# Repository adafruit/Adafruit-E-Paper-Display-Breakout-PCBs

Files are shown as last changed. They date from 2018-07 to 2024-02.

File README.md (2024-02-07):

# Adafruit-E-Paper-Display-Breakout-PCBs
PCB files for Adafruit E-Paper Display Breakouts

Format is EagleCAD schematic and board layout

For more details, check out the product page at

   * https://www.adafruit.com/product/1028   
   * https://www.adafruit.com/product/3625
   * https://www.adafruit.com/product/4086
   * https://www.adafruit.com/product/4098
   * https://www.adafruit.com/product/4196
   * https://www.adafruit.com/product/4777   
   * https://www.adafruit.com/product/4778
   * https://www.adafruit.com/product/4947

Adafruit invests time and resources providing this open source design, 
please support Adafruit and open-source hardware by purchasing 
products from Adafruit!

Designed by Adafruit Industries.  
Creative Commons Attribution, Share-Alike license, check license.txt for more information
All text above must be included in any redistribution

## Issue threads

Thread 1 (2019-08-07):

2.13" diagonal eInk display doesn't work

deryakitis, 2019-08-07:
Hi, I am trying to display a bmp file with 2.13" diagonal e-Ink display by using Metro M4 express boot. When I try the basic code (from CircuitPython website) below, it seems like working well, it follows the code to the end and prints every command they I put in the code on the pc screen. But nothing changes on e-Ink display device.Do you have an idea about how I can make it work?

output:

Auto-reload is on. Simply save files over USB to run them or enter REPL to disable.
code.py output:
Creating display
File opened
Size: 66200
Image offset: 54
Header size: 40
Width: 212
Height: 104
Bit depth: 24
Image OK! Drawing...
Finished drawing
done

code:

import digitalio
import busio
import board
from adafruit_epd.epd import Adafruit_EPD
from adafruit_epd.il0373 import Adafruit_IL0373

spi = busio.SPI(board.SCK, MOSI=board.MOSI, MISO=board.MISO)
ecs = digitalio.DigitalInOut(board.D9)
dc = digitalio.DigitalInOut(board.D10)
srcs = None
rst = None
busy = None

print("Creating display")
display = Adafruit_IL0373(104, 212, spi,         # 2.13" Tri-color display
                          cs_pin=ecs, dc_pin=dc, sramcs_pin=srcs,
                          rst_pin=rst, busy_pin=busy)

display.rotation = 3

FILENAME = "blinka.bmp"

def read_le(s):
    # as of this writting, int.from_bytes does not have LE support, DIY!
    result = 0
    shift = 0
    for byte in bytearray(s):
        result += byte << shift
        shift += 8
    return result

class BMPError(Exception):
    pass

def display_bitmap(epd, filename):

    try:
        f = open("/" + filename, "rb")
    except OSError:
        print("Couldn't open file")
        return

    print("File opened")
    try:
        if f.read(2) != b'BM':  # check signature
            raise BMPError("Not BitMap file")

        bmpFileSize = read_le(f.read(4))
        f.read(4)  # Read & ignore creator bytes

        bmpImageoffset = read_le(f.read(4))  # Start of image data
        headerSize = read_le(f.read(4))
        bmpWidth = read_le(f.read(4))
        bmpHeight = read_le(f.read(4))
        flip = True

        print("Size: %d\nImage offset: %d\nHeader size: %d" %
              (bmpFileSize, bmpImageoffset, headerSize))
        print("Width: %d\nHeight: %d" % (bmpWidth, bmpHeight))

        if read_le(f.read(2)) != 1:
            raise BMPError("Not singleplane")
        bmpDepth = read_le(f.read(2))  # bits per pixel
        print("Bit depth: %d" % (bmpDepth))
        if bmpDepth != 24:
            raise BMPError("Not 24-bit")
        if read_le(f.read(2)) != 0:
            raise BMPError("Compressed file")

        print("Image OK! Drawing...")

        rowSize = (bmpWidth * 3 + 3) & ~3  # 32-bit line boundary

        for row in range(bmpHeight):  # For each scanline...
            if flip:  # Bitmap is stored bottom-to-top order (normal BMP)
                pos = bmpImageoffset + (bmpHeight - 1 - row) * rowSize
            else:  # Bitmap is stored top-to-bottom
                pos = bmpImageoffset + row * rowSize

            f.seek(pos)
            rowdata = f.read(3*bmpWidth)
            for col in range(bmpWidth):
                b, g, r = rowdata[3*col:3*col+3]  # BMP files store RGB in BGR
                if r < 0x80 and g < 0x80 and b < 0x80:
                    epd.pixel(col, row, Adafruit_EPD.BLACK)
                elif r >= 0x80 and g >= 0x80 and b >= 0x80:
                    pass  # epd.pixel(row, col, Adafruit_EPD.WHITE)
                elif r >= 0x80:
                    epd.pixel(col, row, Adafruit_EPD.RED)
    except OSError:
        print("Couldn't read file")
    except BMPError as e:
        print("Failed to parse BMP: " + e.args[0])
    finally:
        f.close()
    print("Finished drawing")

display.fill(Adafruit_EPD.WHITE)
display_bitmap(display, FILENAME)
display.display()

print  ("done")

ladyada, 2019-08-07:
hiya please post photos and details on the forums for tech support. thnkx!

deryakitis, 2019-08-07:
I attached the photos of the set-up!

ladyada, 2019-08-07:
hiya please post photos and details on the forums for tech support. thnkx!

caternuson, 2019-08-07:
Forums are here:
https://forums.adafruit.com/

Closed 2019-08-07.

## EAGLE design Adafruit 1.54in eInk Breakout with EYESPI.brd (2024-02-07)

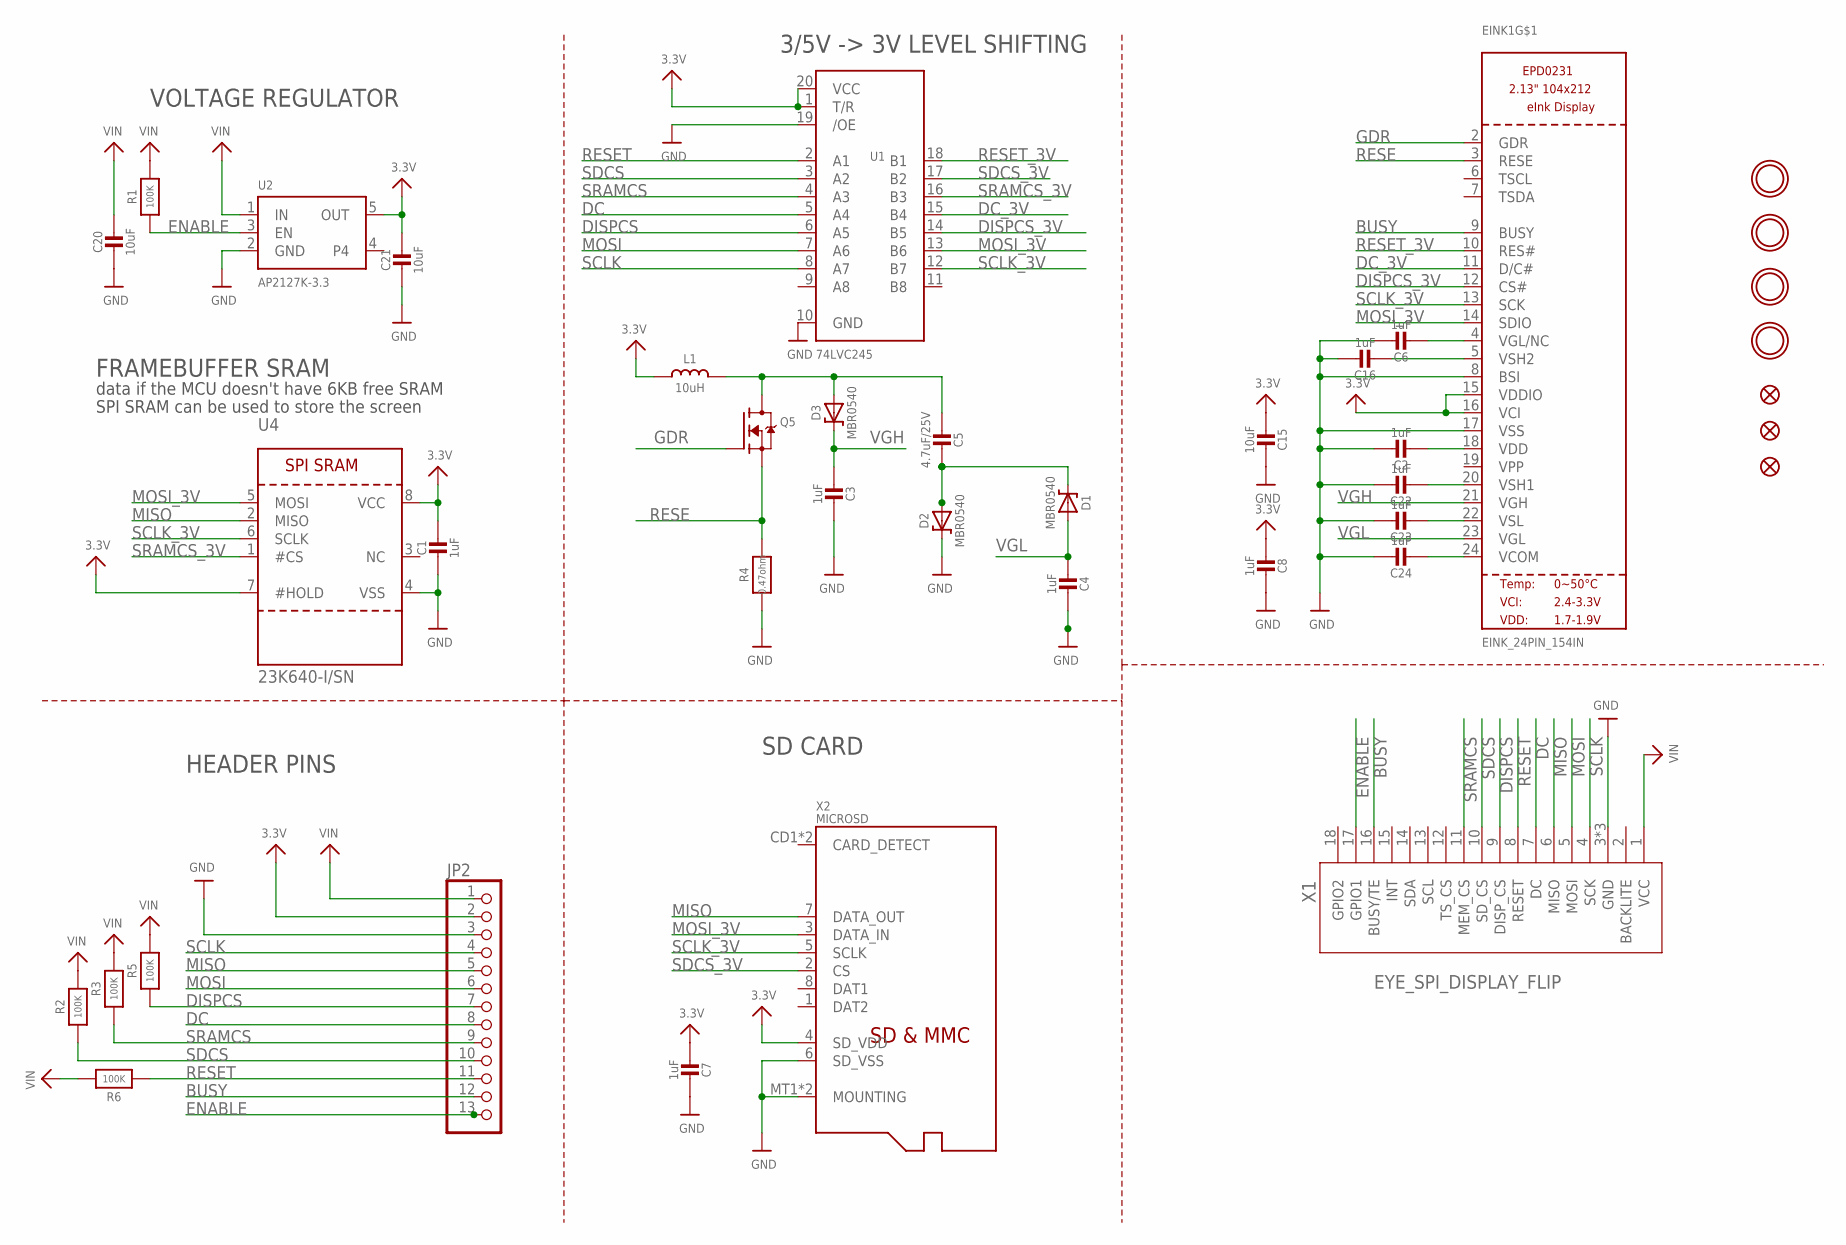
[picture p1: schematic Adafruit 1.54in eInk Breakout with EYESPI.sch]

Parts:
C1, C2, C3, C4, C6, C7, C8, C16, C22, C23, C24: 1uF; 0805-NO
C5: 4.7uF/25V; 0805-NO
C15, C20, C21: 10uF; 0805-NO
D1, D2, D3: MBR0540; SOD-123
EINK1: EINK_24PIN_154IN; EINK_154IN
FID1, FID2, FID3: FIDUCIAL_1MM
JP2: HEADER-1X13; 1X13_ROUND_70
L1: 10uH; INDUCTOR_4X4MM_NR401
Q5: IRLML0100; SOT23-3
R1, R2, R3, R5, R6: 100K; 0805-NO
R4: 0.47ohm; 0805_10MGAP
U1: 74LVC245; TSSOP20
U2: AP2127K-3.3; SOT23-5
U4: 23K640-I/SN; SOIC8_150MIL
U$3, U$4, U$5, U$6: MOUNTINGHOLE2.5; MOUNTINGHOLE_2.5_PLATED
X1: EYE_SPI_DISPLAY_FLIP; EYE_SPI_DISPLAY_BOTCONTACT
X2: MICROSD

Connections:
3.3V: C1.1, C7.1, C8.1, C15.2, C21.1, EINK1.15 (VDDIO), EINK1.16 (VCI), JP2.2, L1.P$2 (2), U1.1 (T/R), U1.20 (VCC), U2.5 (OUT), U4.7 (#HOLD), U4.8 (VCC), X2.4 (SD_VDD)
BUSY: EINK1.9 (BUSY), JP2.12, X1.16 (BUSY/TE)
DC: JP2.8, U1.5 (A4), X1.7 (DC)
DC_3V: EINK1.11 (D/C#), U1.15 (B4)
DISPCS: JP2.7, R5.1, U1.6 (A5), X1.9 (DISP_CS)
DISPCS_3V: EINK1.12 (CS#), U1.14 (B5)
ENABLE: JP2.13, R1.1, U2.3 (EN), X1.17 (GPIO1)
GDR: EINK1.2 (GDR), Q5.1 (G)
GND: C1.2, C2.1, C3.2, C4.2, C6.1, C7.2, C8.2, C15.1, C16.1, C20.2, C21.2, C22.1, C23.1, C24.1, D2.C, EINK1.8 (BSI), EINK1.17 (VSS), JP2.3, R4.2, U1.10 (GND), U1.19 (/OE), U2.2 (GND), U4.4 (VSS), X1.3 (GND), X1.SUPPORT1 (GND), X1.SUPPORT2 (GND), X2.6 (SD_VSS), X2.MT1 (MOUNTING), X2.MT2 (MOUNTING)
MISO: JP2.5, U4.2 (MISO), X1.6 (MISO), X2.7 (DATA_OUT)
MOSI: JP2.6, U1.7 (A6), X1.5 (MOSI)
MOSI_3V: EINK1.14 (SDIO), U1.13 (B6), U4.5 (MOSI), X2.3 (DATA_IN)
unnamed: C5.2, D1.C, D2.A
unnamed: C5.1, D3.A, L1.P$1 (1), Q5.3 (D)
unnamed: C16.2, EINK1.5 (VSH2)
unnamed: C2.2, EINK1.18 (VDD)
unnamed: C22.2, EINK1.20 (VSH1)
unnamed: C6.2, EINK1.4 (VGL/NC)
unnamed: C23.2, EINK1.22 (VSL)
unnamed: C24.2, EINK1.24 (VCOM)
RESE: EINK1.3 (RESE), Q5.2 (S), R4.1
RESET: JP2.11, R6.1, U1.2 (A1), X1.8 (RESET)
RESET_3V: EINK1.10 (RES#), U1.18 (B1)
SCLK: JP2.4, U1.8 (A7), X1.4 (SCK)
SCLK_3V: EINK1.13 (SCK), U1.12 (B7), U4.6 (SCLK), X2.5 (SCLK)
SDCS: JP2.10, R2.1, U1.3 (A2), X1.10 (SD_CS)
SDCS_3V: U1.17 (B2), X2.2 (CS)
SRAMCS: JP2.9, R3.1, U1.4 (A3), X1.11 (MEM_CS)
SRAMCS_3V: U1.16 (B3), U4.1 (#CS)
VGH: C3.1, D3.C, EINK1.21 (VGH)
VGL: C4.1, D1.A, EINK1.23 (VGL)
VIN: C20.1, JP2.1, R1.2, R2.2, R3.2, R5.2, R6.2, U2.1 (IN), X1.1 (VCC)

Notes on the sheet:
VOLTAGE REGULATOR
3/5V -> 3V LEVEL SHIFTING
HEADER PINS
FRAMEBUFFER SRAM
SPI SRAM can be used to store the screen
data if the MCU doesn't have 6KB free SRAM
SD CARD

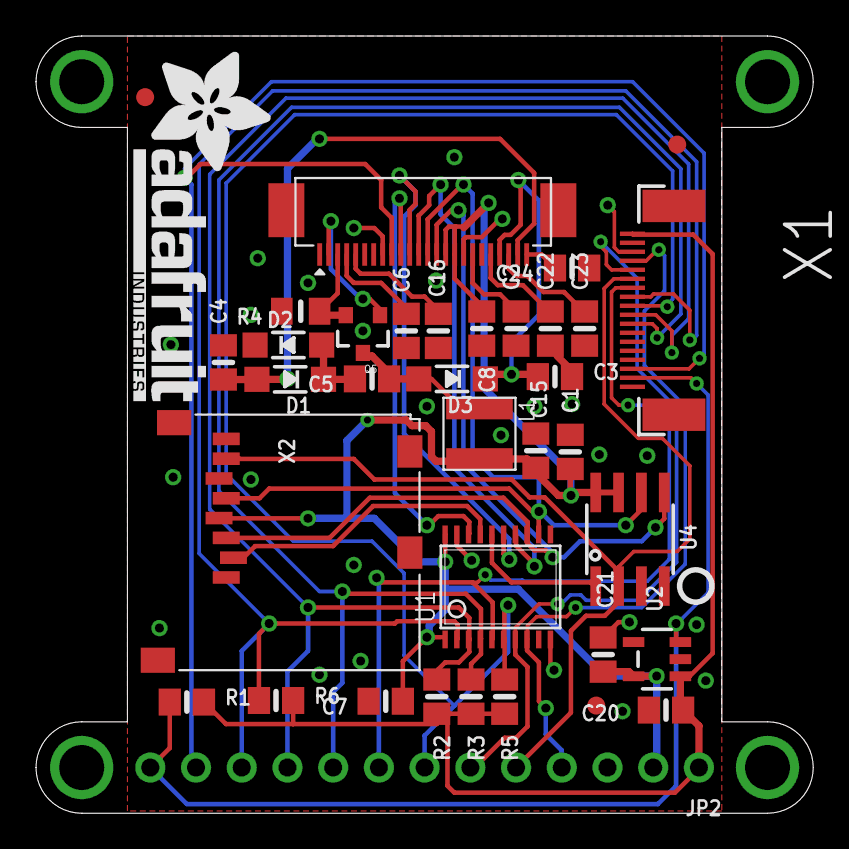
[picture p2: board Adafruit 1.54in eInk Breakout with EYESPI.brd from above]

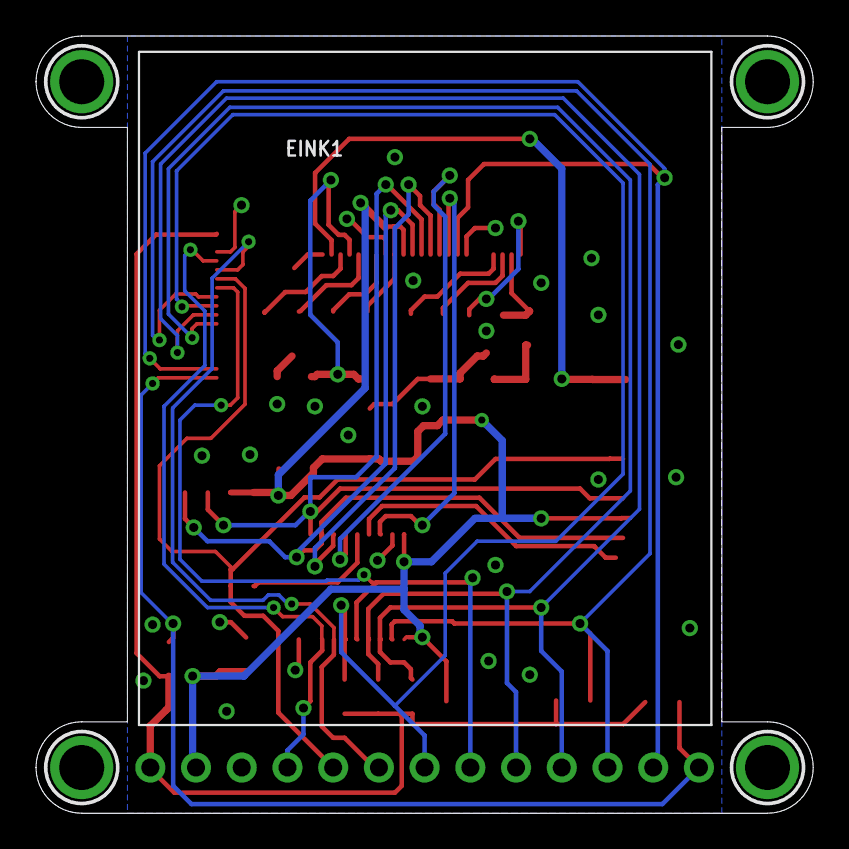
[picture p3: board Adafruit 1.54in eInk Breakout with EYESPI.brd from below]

Board: 2 copper layers, 43.2 x 43.2 mm, 70 parts (18 on the bottom side), 32 nets.

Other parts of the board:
PLABEL0: PLABEL0
PLABEL1: PLABEL1
PLABEL2: PLABEL2
PLABEL3: PLABEL3
PLABEL4: PLABEL4
PLABEL5: PLABEL5
PLABEL6: PLABEL6
PLABEL7: PLABEL7
PLABEL8: PLABEL8
PLABEL9: PLABEL9
PLABEL10: PLABEL10
PLABEL11: PLABEL11
PLABEL12: PLABEL12
PLABEL13: PLABEL13
PLABEL14: PLABEL14
PLABEL15: PLABEL15
PLABEL16: PLABEL16
PLABEL17: PLABEL17
PLABEL18: PLABEL18
PLABEL19: PLABEL19
PLABEL20: PLABEL20
PLABEL21: PLABEL21
PLABEL22: PLABEL22
PLABEL23: PLABEL23
PLABEL24: PLABEL24
PLABEL25: PLABEL25
PLABEL26: PLABEL26
PLABEL27: PLABEL27
U$9: PCBFEAT-REV-040
U$28: ADAFRUIT_TEXT_20MM

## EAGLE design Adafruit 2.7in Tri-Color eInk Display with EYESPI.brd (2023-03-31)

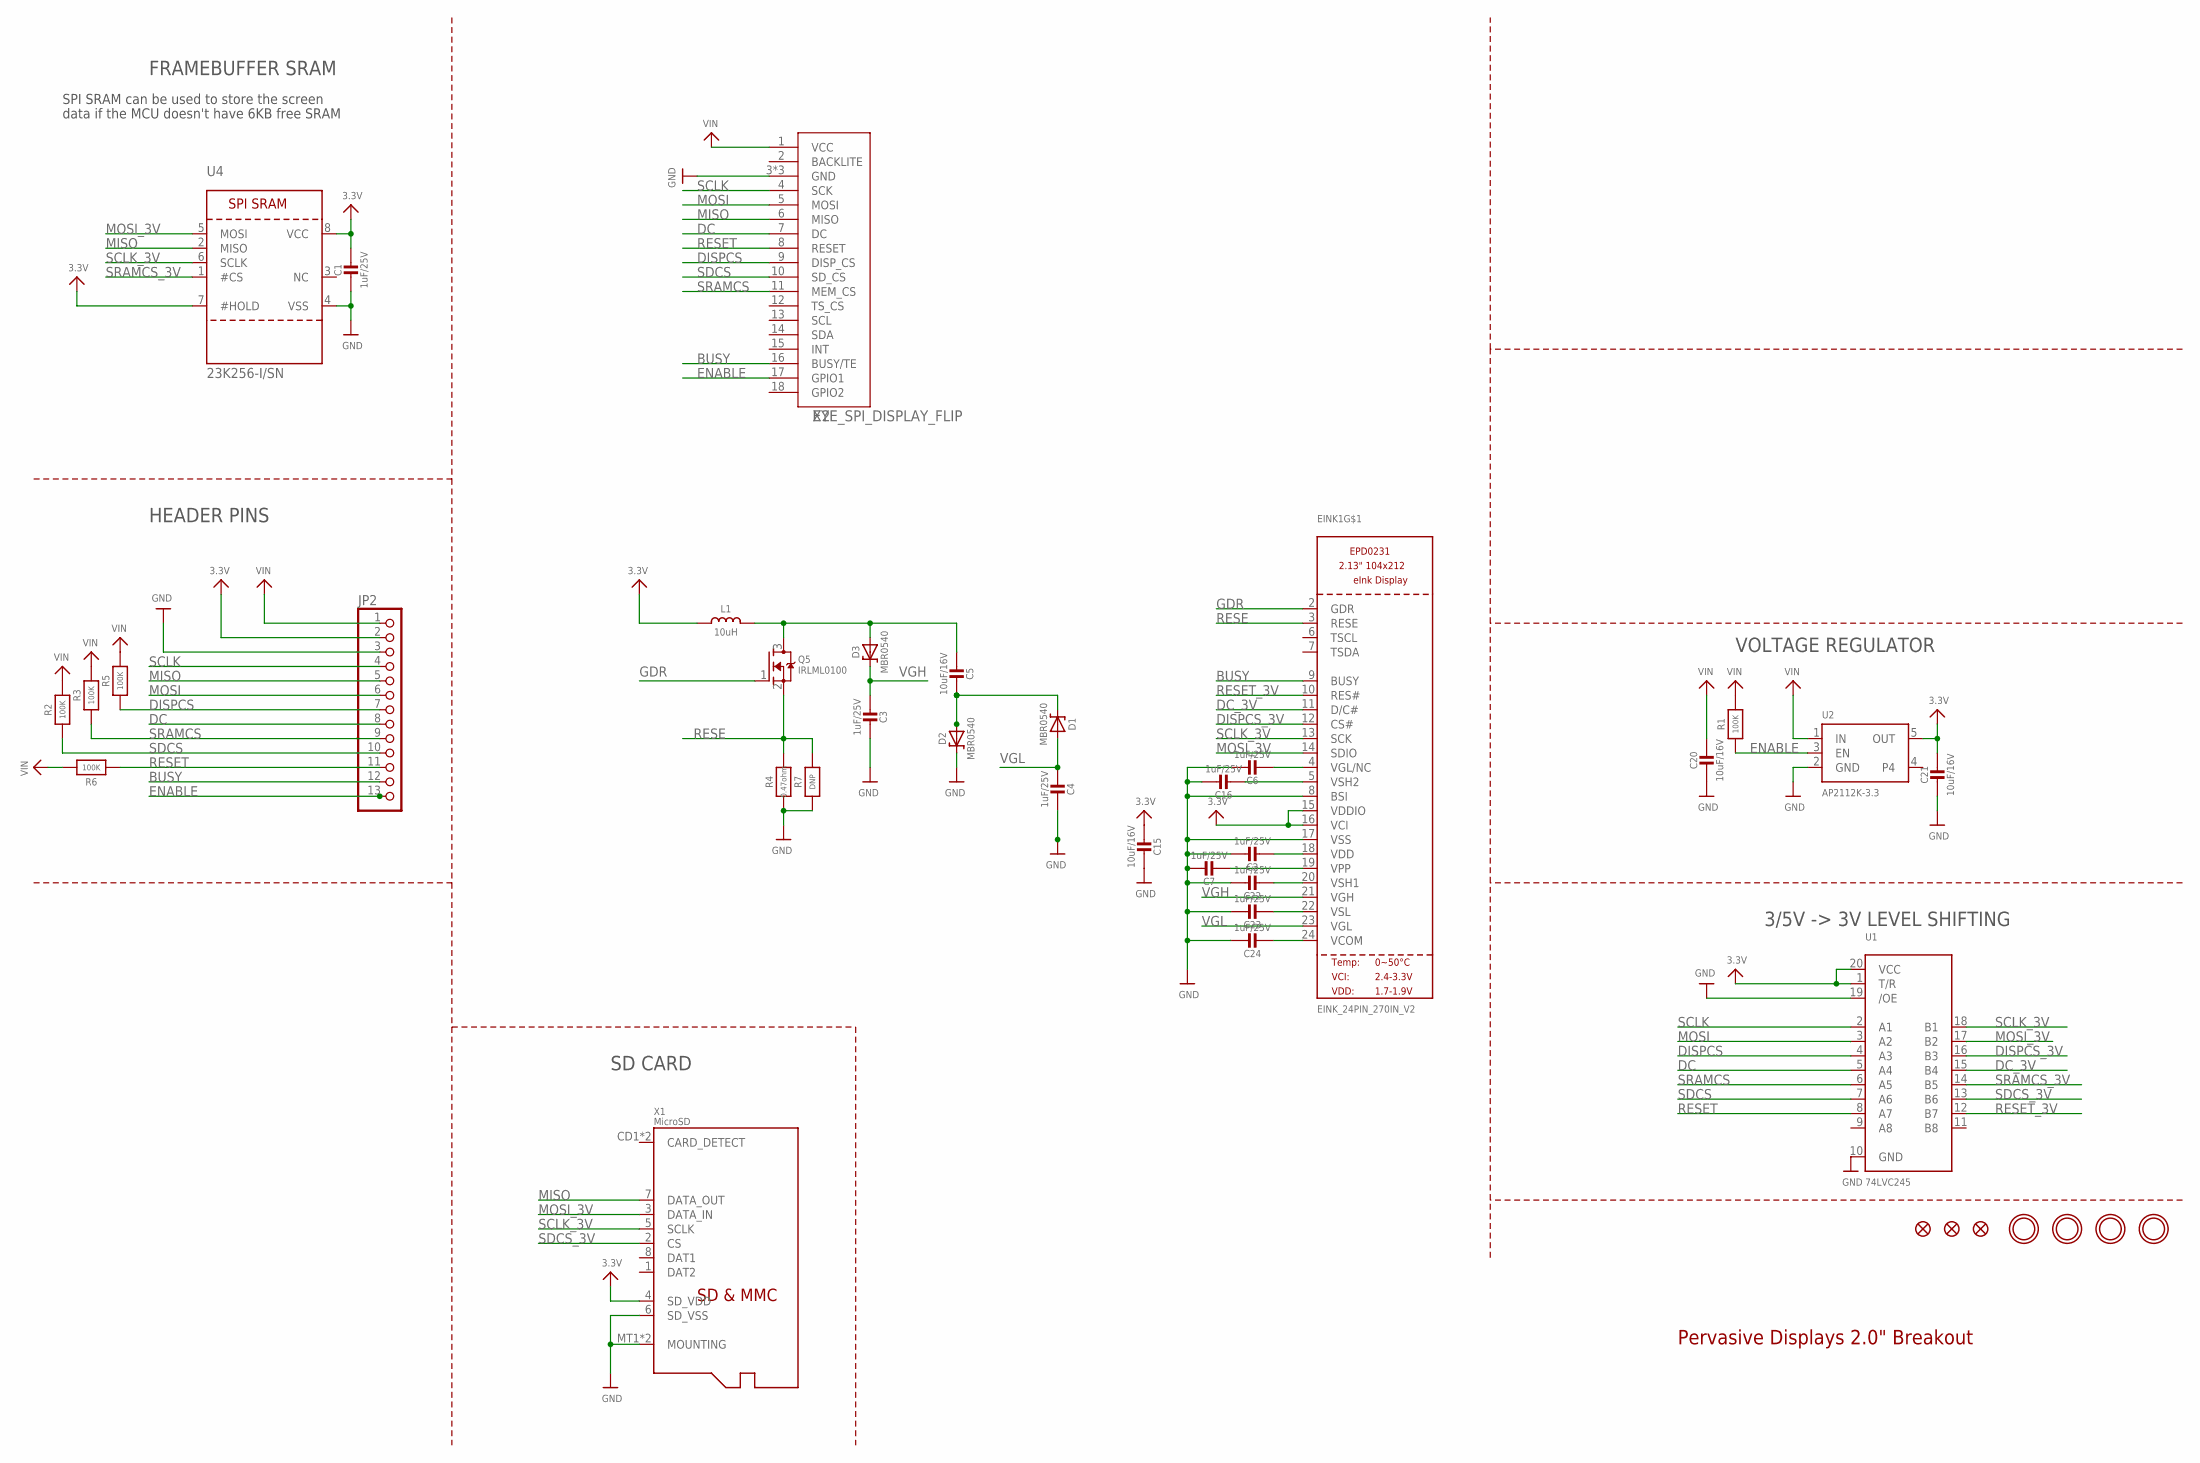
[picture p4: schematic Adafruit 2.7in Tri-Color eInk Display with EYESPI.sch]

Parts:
C1, C2, C3, C4, C6, C7, C16, C22, C23, C24: 1uF/25V; 0603-NO
C5, C15, C20, C21: 10uF/16V; 0805-NO
D1, D2, D3: MBR0540; SOD-123
EINK1: EINK_24PIN_270IN_V2; EINK_270IN_V2
FID1, FID2, FID3: FIDUCIAL_1MM
JP2: HEADER-1X13; 1X13_ROUND_70
L1: 10uH; INDUCTOR_4X4MM_NR401
Q5: IRLML0100; SOT23-WIDE
R1, R2, R3, R5, R6: 100K; 0603-NO
R4: 0.47ohm; 0603-NO
R7: DNP; 0603-NO
U1: 74LVC245; TSSOP20
U2: AP2112K-3.3; SOT23-5; JLC_ROTATION 0
U4: 23K256-I/SN; SOIC8_150MIL
U$3, U$4, U$5, U$6: MOUNTINGHOLE2.5; MOUNTINGHOLE_2.5_PLATED
X1: MicroSD; MICROSD
X2: EYE_SPI_DISPLAY_FLIP; EYE_SPI_DISPLAY_BOTCONTACT

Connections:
3.3V: C1.1, C15.2, C21.1, EINK1.15 (VDDIO), EINK1.16 (VCI), JP2.2, L1.P$2 (2), U1.1 (T/R), U1.20 (VCC), U2.5 (OUT), U4.7 (#HOLD), U4.8 (VCC), X1.4 (SD_VDD)
BUSY: EINK1.9 (BUSY), JP2.12, X2.16 (BUSY/TE)
DC: JP2.8, U1.5 (A4), X2.7 (DC)
DC_3V: EINK1.11 (D/C#), U1.15 (B4)
DISPCS: JP2.7, R5.1, U1.4 (A3), X2.9 (DISP_CS)
DISPCS_3V: EINK1.12 (CS#), U1.16 (B3)
ENABLE: JP2.13, R1.1, U2.3 (EN), X2.17 (GPIO1)
GDR: EINK1.2 (GDR), Q5.1 (G)
GND: C1.2, C2.1, C3.2, C4.2, C6.1, C7.1, C15.1, C16.1, C20.2, C21.2, C22.1, C23.1, C24.1, D2.C, EINK1.8 (BSI), EINK1.17 (VSS), JP2.3, R4.2, R7.2, U1.10 (GND), U1.19 (/OE), U2.2 (GND), U4.4 (VSS), X1.6 (SD_VSS), X1.MT1 (MOUNTING), X1.MT2 (MOUNTING), X2.3 (GND), X2.SUPPORT1 (GND), X2.SUPPORT2 (GND)
MISO: JP2.5, U4.2 (MISO), X1.7 (DATA_OUT), X2.6 (MISO)
MOSI: JP2.6, U1.3 (A2), X2.5 (MOSI)
MOSI_3V: EINK1.14 (SDIO), U1.17 (B2), U4.5 (MOSI), X1.3 (DATA_IN)
unnamed: C7.2, EINK1.19 (VPP)
unnamed: C5.2, D1.C, D2.A
unnamed: C5.1, D3.A, L1.P$1 (1), Q5.3 (D)
unnamed: C16.2, EINK1.5 (VSH2)
unnamed: C2.2, EINK1.18 (VDD)
unnamed: C22.2, EINK1.20 (VSH1)
unnamed: C6.2, EINK1.4 (VGL/NC)
unnamed: C23.2, EINK1.22 (VSL)
unnamed: C24.2, EINK1.24 (VCOM)
RESE: EINK1.3 (RESE), Q5.2 (S), R4.1, R7.1
RESET: JP2.11, R6.1, U1.8 (A7), X2.8 (RESET)
RESET_3V: EINK1.10 (RES#), U1.12 (B7)
SCLK: JP2.4, U1.2 (A1), X2.4 (SCK)
SCLK_3V: EINK1.13 (SCK), U1.18 (B1), U4.6 (SCLK), X1.5 (SCLK)
SDCS: JP2.10, R2.1, U1.7 (A6), X2.10 (SD_CS)
SDCS_3V: U1.13 (B6), X1.2 (CS)
SRAMCS: JP2.9, R3.1, U1.6 (A5), X2.11 (MEM_CS)
SRAMCS_3V: U1.14 (B5), U4.1 (#CS)
VGH: C3.1, D3.C, EINK1.21 (VGH)
VGL: C4.1, D1.A, EINK1.23 (VGL)
VIN: C20.1, JP2.1, R1.2, R2.2, R3.2, R5.2, R6.2, U2.1 (IN), X2.1 (VCC)

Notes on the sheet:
Pervasive Displays 2.0" Breakout
VOLTAGE REGULATOR
3/5V -> 3V LEVEL SHIFTING
HEADER PINS
FRAMEBUFFER SRAM
SPI SRAM can be used to store the screen
data if the MCU doesn't have 6KB free SRAM
SD CARD

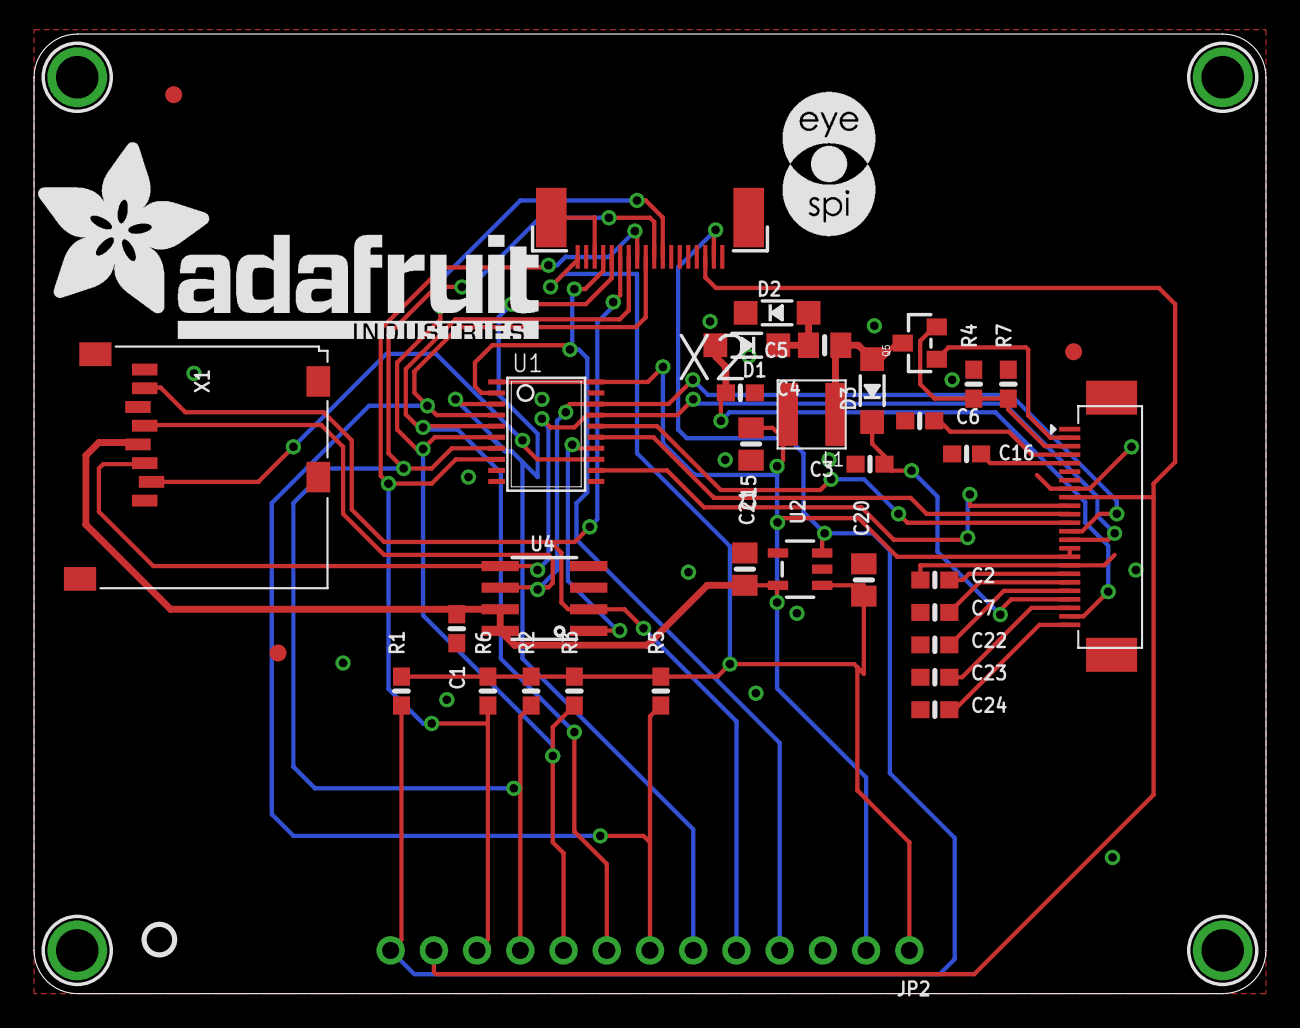
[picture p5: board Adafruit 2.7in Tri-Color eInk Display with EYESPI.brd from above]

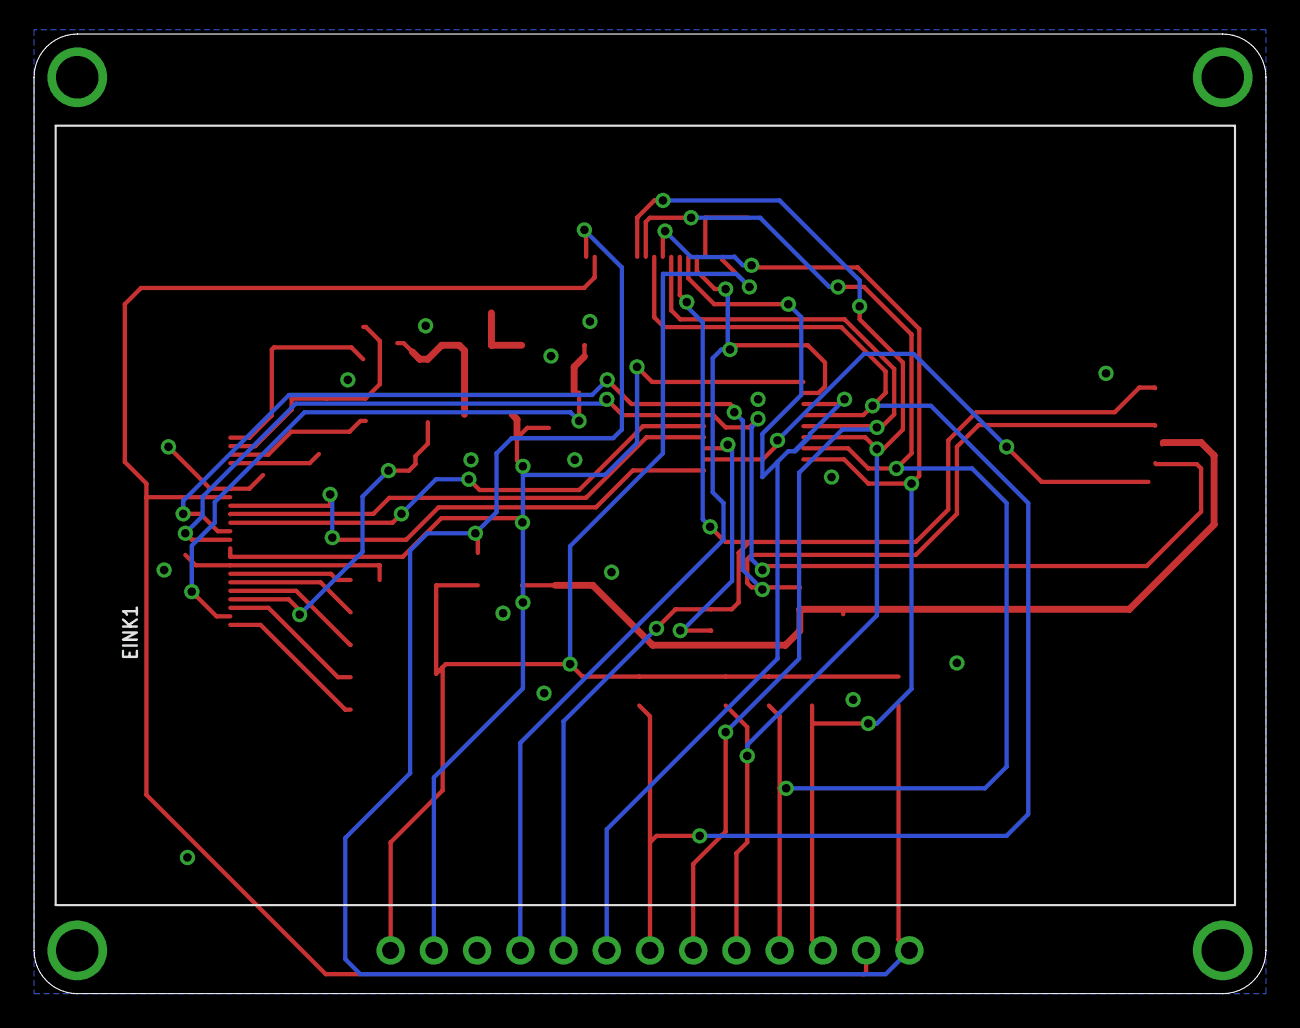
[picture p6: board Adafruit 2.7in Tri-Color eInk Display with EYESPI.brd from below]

Board: 2 copper layers, 72.4 x 56.4 mm, 72 parts (15 on the bottom side), 33 nets.

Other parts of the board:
PLABEL0: PLABEL0
PLABEL1: PLABEL1
PLABEL2: PLABEL2
PLABEL3: PLABEL3
PLABEL4: PLABEL4
PLABEL5: PLABEL5
PLABEL6: PLABEL6
PLABEL7: PLABEL7
PLABEL8: PLABEL8
PLABEL9: PLABEL9
PLABEL10: PLABEL10
PLABEL11: PLABEL11
PLABEL12: PLABEL12
PLABEL13: PLABEL13
PLABEL14: PLABEL14
PLABEL15: PLABEL15
PLABEL16: PLABEL16
PLABEL17: PLABEL17
PLABEL18: PLABEL18
PLABEL19: PLABEL19
PLABEL20: PLABEL20
PLABEL21: PLABEL21
PLABEL22: PLABEL22
PLABEL23: PLABEL23
PLABEL24: PLABEL24
PLABEL25: PLABEL25
PLABEL26: PLABEL26
PLABEL27: PLABEL27
PLABEL28: PLABEL28
U$1: EYESPI_MINI_LOGO
U$9: PCBFEAT-REV-040
U$39: ADAFRUIT_TEXT_30MM

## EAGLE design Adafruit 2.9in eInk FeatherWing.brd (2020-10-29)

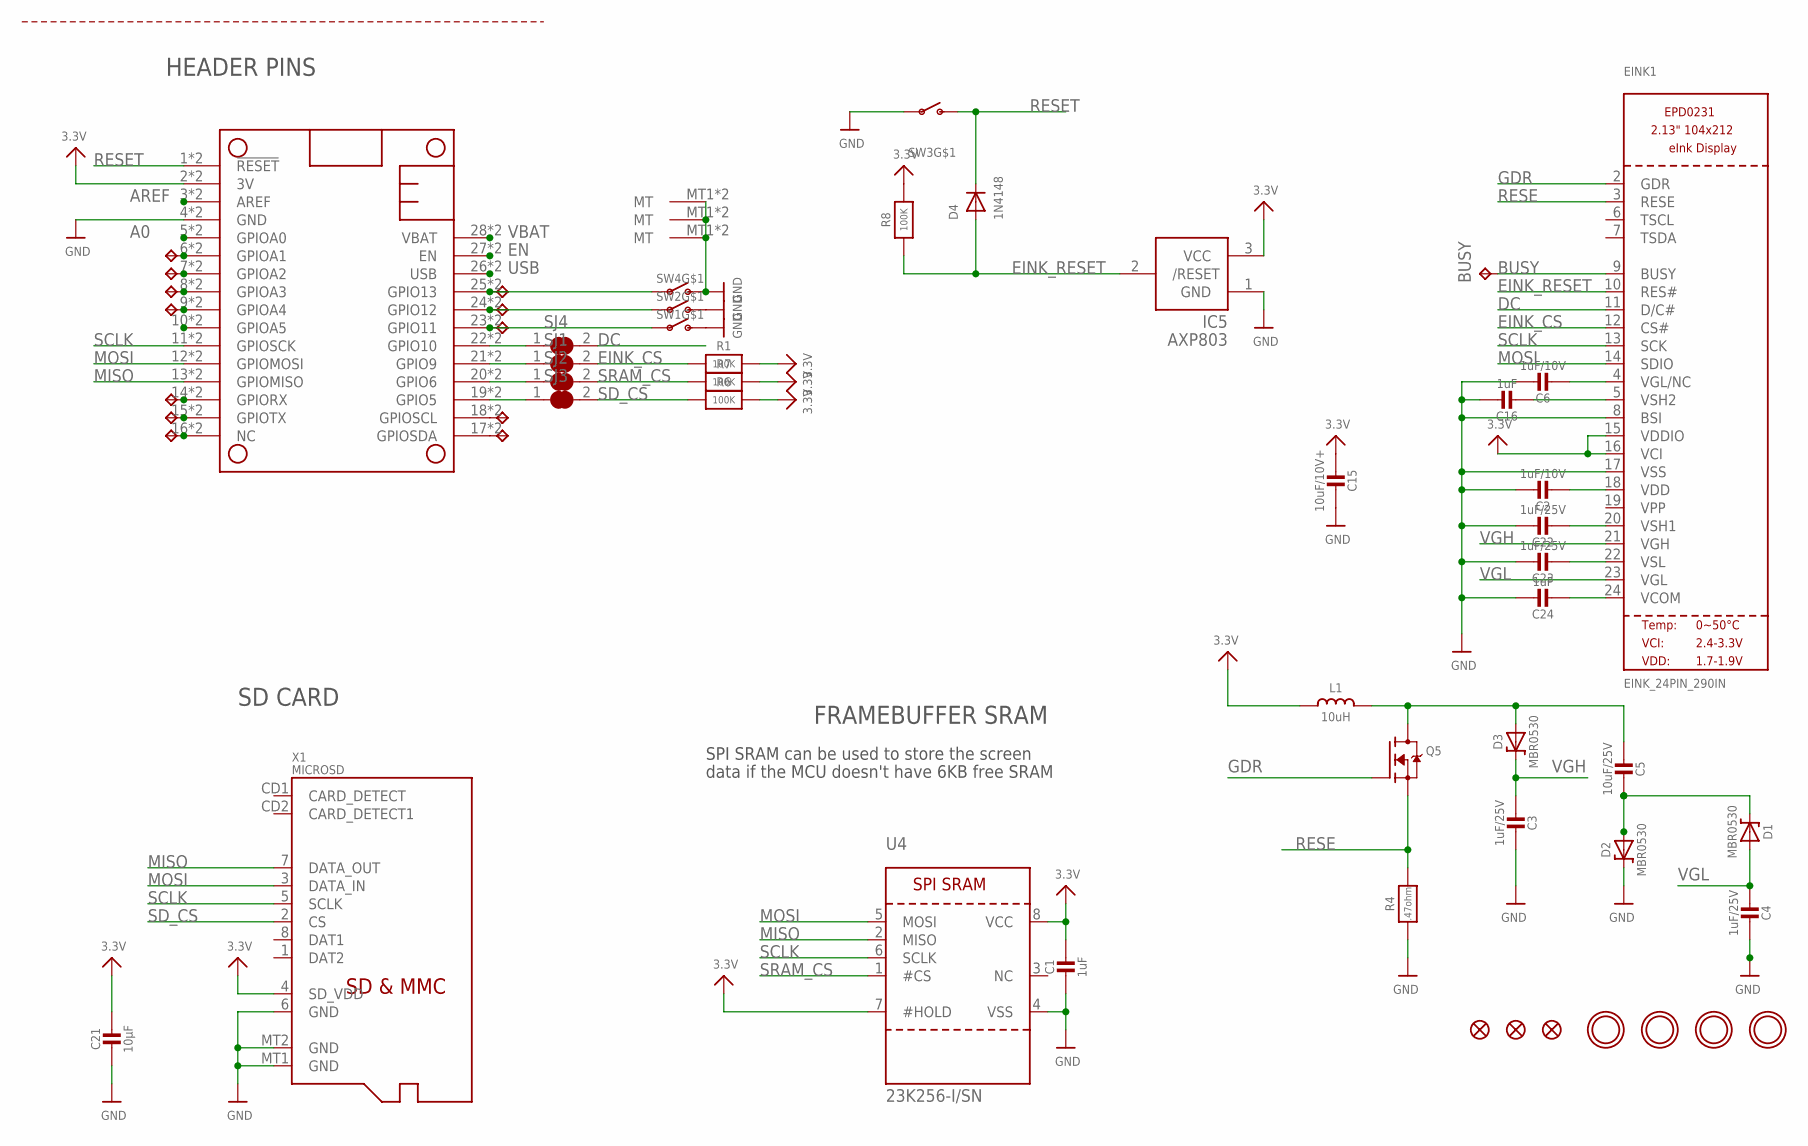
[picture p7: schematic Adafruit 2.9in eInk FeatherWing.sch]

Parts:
BUSY: TPTP15SQ; TP15SQ
C1: 1uF; 0805_10MGAP
C2, C6: 1uF/10V; 0805-NO
C3, C4, C22, C23: 1uF/25V; 0805-NO
C5: 10uF/25V; 0805-NO
C15: 10uF/10V+; 0805-NO
C16, C24: 1uF; 0805-NO
C21: 10µF; 0805-NO
D1, D2, D3: MBR0530; SOD-123
D4: 1N4148; SOD-323F
EINK1: EINK_24PIN_290IN; EINK_290IN
FID1, FID2, FID3: FIDUCIAL_1MM
IC5: AXP803; SOT23
L1: 10uH; INDUCTOR_4X4MM_NR401
MS1: FEATHERWING_SMTDUALNOHOLES; FEATHERWING_SMT_NOHOLES
Q5: IRLML0100; SOT23-3
R1, R6, R7, R8: 100K; 0603-NO
R4: .47ohm; 0805_10MGAP
SJ1, SJ2, SJ3, SJ4: SOLDERJUMPER_CLOSED; SOLDERJUMPER_CLOSEDWIRE
SW1, SW2, SW3, SW4: SWITCH_SPST_TACT_RA; SPST_TACTILE_RA
TP1, TP2, TP3, TP4, TP5, TP6, TP7, TP8, TP9, TP11, TP12, TP13: TPTP15SQ; TP15SQ
U4: 23K256-I/SN; SOIC8_150MIL
U$3, U$4, U$5, U$6: MOUNTINGHOLE2.5; MOUNTINGHOLE_2.5_PLATED
X1: MICROSD

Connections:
3.3V: C1.1, C15.2, C21.1, EINK1.15 (VDDIO), EINK1.16 (VCI), IC5.3 (VCC), L1.P$2 (2), MS1.2 (3V), MS1.2B (3V), R1.2, R6.2, R7.2, R8.2, U4.7 (#HOLD), U4.8 (VCC), X1.4 (SD_VDD)
A0: MS1.5 (GPIOA0), MS1.5B (GPIOA0)
AREF: MS1.3 (AREF), MS1.3B (AREF)
BUSY: BUSY.TP, EINK1.9 (BUSY)
DC: EINK1.11 (D/C#), SJ4.2
EINK_CS: EINK1.12 (CS#), R1.1, SJ1.2
EINK_RESET: D4.A, EINK1.10 (RES#), IC5.2 (/RESET), R8.1
EN: MS1.27 (EN), MS1.27B (EN)
GDR: EINK1.2 (GDR), Q5.1 (G)
GND: C1.2, C2.1, C3.2, C4.2, C6.1, C15.1, C16.1, C21.2, C22.1, C23.1, C24.1, D2.C, EINK1.8 (BSI), EINK1.17 (VSS), IC5.1 (GND), MS1.4 (GND), MS1.4B (GND), R4.2, SW1.2 (S), SW1.MT1 (MT), SW1.MT2 (MT), SW2.2 (S), SW2.MT1 (MT), SW2.MT2 (MT), SW3.1, SW4.2 (S), SW4.MT1 (MT), SW4.MT2 (MT), U4.4 (VSS), X1.6 (GND), X1.MT1 (GND), X1.MT2 (GND)
H: MS1.19 (GPIO5), MS1.19B (GPIO5), SJ3.1
I: MS1.20 (GPIO6), MS1.20B (GPIO6), SJ2.1
J: MS1.21 (GPIO9), MS1.21B (GPIO9), SJ1.1
K: MS1.22 (GPIO10), MS1.22B (GPIO10), SJ4.1
MISO: MS1.13 (GPIOMISO), MS1.13B (GPIOMISO), U4.2 (MISO), X1.7 (DATA_OUT)
MOSI: EINK1.14 (SDIO), MS1.12 (GPIOMOSI), MS1.12B (GPIOMOSI), U4.5 (MOSI), X1.3 (DATA_IN)
unnamed: MS1.10 (GPIOA5), MS1.10B (GPIOA5)
unnamed: C5.2, D1.C, D2.A
unnamed: C5.1, D3.A, L1.P$1 (1), Q5.3 (D)
unnamed: C16.2, EINK1.5 (VSH2)
unnamed: C2.2, EINK1.18 (VDD)
unnamed: C22.2, EINK1.20 (VSH1)
unnamed: MS1.6 (GPIOA1), MS1.6B (GPIOA1), TP6.TP
unnamed: C6.2, EINK1.4 (VGL/NC)
unnamed: MS1.7 (GPIOA2), MS1.7B (GPIOA2), TP7.TP
unnamed: MS1.8 (GPIOA3), MS1.8B (GPIOA3), TP8.TP
unnamed: MS1.9 (GPIOA4), MS1.9B (GPIOA4), TP9.TP
unnamed: MS1.14 (GPIORX), MS1.14B (GPIORX), TP11.TP
unnamed: MS1.15 (GPIOTX), MS1.15B (GPIOTX), TP12.TP
unnamed: MS1.16 (NC), MS1.16B (NC), TP13.TP
unnamed: MS1.17 (GPIOSDA), MS1.17B (GPIOSDA), TP4.TP
unnamed: MS1.18 (GPIOSCL), MS1.18B (GPIOSCL), TP3.TP
unnamed: MS1.23 (GPIO11), MS1.23B (GPIO11), SW1.1, TP1.TP
unnamed: MS1.24 (GPIO12), MS1.24B (GPIO12), SW2.1, TP2.TP
unnamed: MS1.25 (GPIO13), MS1.25B (GPIO13), SW4.1, TP5.TP
unnamed: C23.2, EINK1.22 (VSL)
unnamed: C24.2, EINK1.24 (VCOM)
RESE: EINK1.3 (RESE), Q5.2 (S), R4.1
RESET: D4.C, MS1.1 (!RESET), MS1.1B (!RESET), SW3.2 (S)
SCLK: EINK1.13 (SCK), MS1.11 (GPIOSCK), MS1.11B (GPIOSCK), U4.6 (SCLK), X1.5 (SCLK)
SD_CS: R6.1, SJ3.2, X1.2 (CS)
SRAM_CS: R7.1, SJ2.2, U4.1 (#CS)
USB: MS1.26 (USB), MS1.26B (USB)
VBAT: MS1.28 (VBAT), MS1.28B (VBAT)
VGH: C3.1, D3.C, EINK1.21 (VGH)
VGL: C4.1, D1.A, EINK1.23 (VGL)

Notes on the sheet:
HEADER PINS
FRAMEBUFFER SRAM
SPI SRAM can be used to store the screen
data if the MCU doesn't have 6KB free SRAM
SD CARD

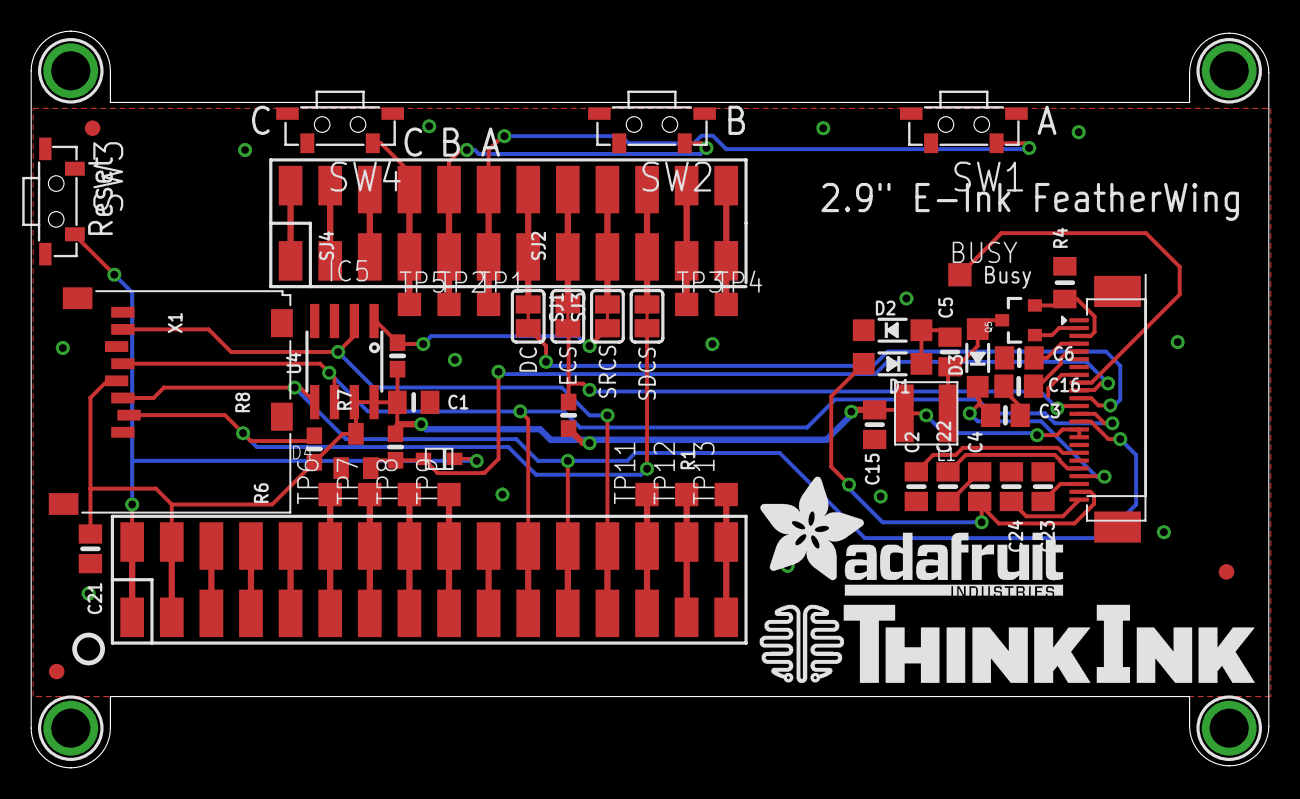
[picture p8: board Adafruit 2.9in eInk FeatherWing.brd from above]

Board: 2 copper layers, 79.4 x 47.2 mm, 59 parts (1 on the bottom side), 46 nets.

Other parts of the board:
U$8: THINKINK_1.25IN
U$9: PCBFEAT-REV-040
U$17: ADAFRUIT_TEXT_20MM

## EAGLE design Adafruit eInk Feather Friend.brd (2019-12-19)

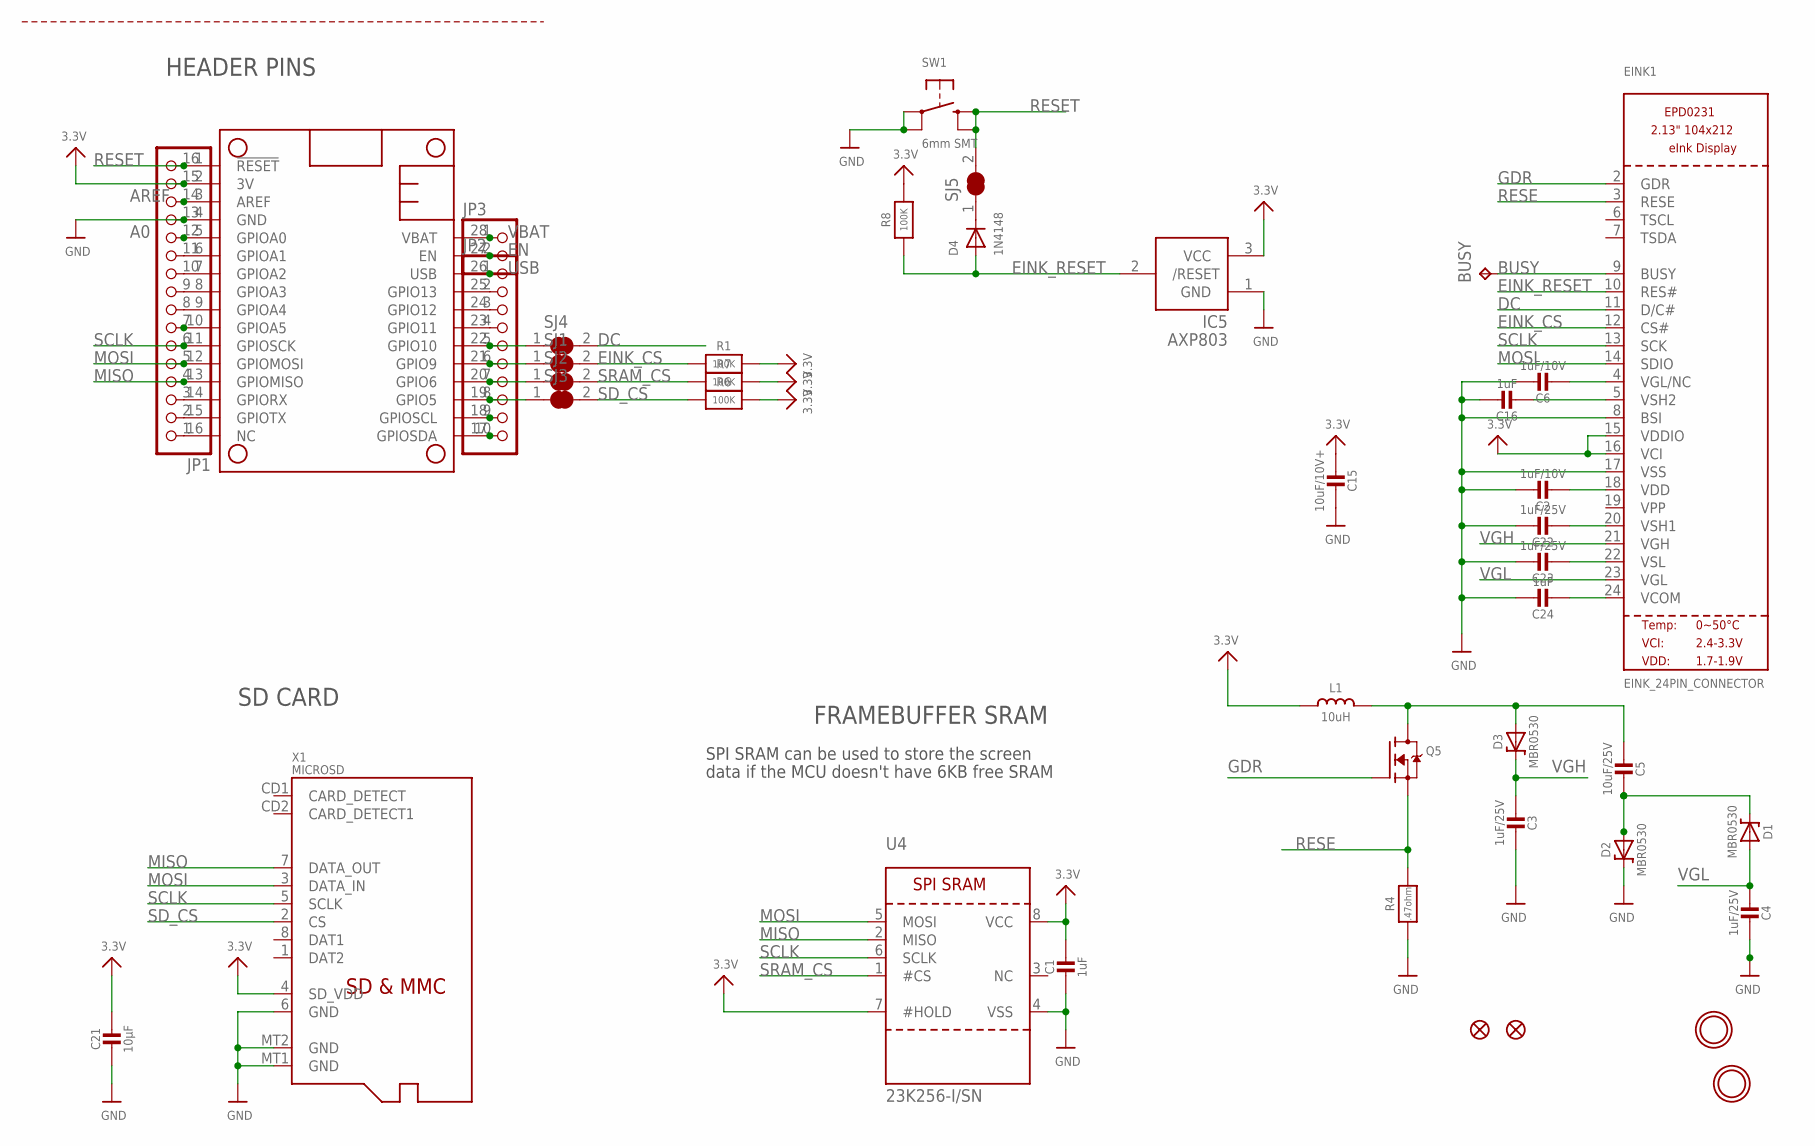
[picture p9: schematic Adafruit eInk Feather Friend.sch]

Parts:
BUSY: TPTP15SQ; TP15SQ
C1: 1uF; 0805_10MGAP
C2, C6: 1uF/10V; 0805-NO
C3, C4, C22, C23: 1uF/25V; 0805-NO
C5: 10uF/25V; 0805-NO
C15: 10uF/10V+; 0805-NO
C16, C24: 1uF; 0805-NO
C21: 10µF; 0805-NO
D1, D2, D3: MBR0530; SOD-123
D4: 1N4148; SOD-323F
EINK1: EINK_24PIN_CONNECTOR; EINK_24PIN
FID1, FID3: FIDUCIAL_1MM
IC5: AXP803; SOT23
JP1: HEADER-1X16ROUND; 1X16_ROUND
JP2: HEADER-1X10ROUND; 1X10_ROUND
JP3: HEADER-1X2ROUND; 1X02_ROUND
L1: 10uH; INDUCTOR_4X4MM_NR401
MS1: FEATHERWING_NOHOLES
Q5: IRLML0100; SOT23-3
R1, R6, R7, R8: 100K; 0603-NO
R4: .47ohm; 0805_10MGAP
SJ1, SJ2, SJ3, SJ4, SJ5: SOLDERJUMPER_CLOSED; SOLDERJUMPER_CLOSEDWIRE
SW1: 6mm SMT; BTN_KMR2_4.6X2.8
U4: 23K256-I/SN; SOIC8_150MIL
U$3, U$4: MOUNTINGHOLE2.5; MOUNTINGHOLE_2.5_PLATED
X1: MICROSD

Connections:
3.3V: C1.1, C15.2, C21.1, EINK1.15 (VDDIO), EINK1.16 (VCI), IC5.3 (VCC), JP1.15, L1.P$2 (2), MS1.2 (3V), R1.2, R6.2, R7.2, R8.2, U4.7 (#HOLD), U4.8 (VCC), X1.4 (SD_VDD)
A0: JP1.12, MS1.5 (GPIOA0)
AREF: JP1.14, MS1.3 (AREF)
BUSY: BUSY.TP, EINK1.9 (BUSY)
DC: EINK1.11 (D/C#), SJ4.2
EINK_CS: EINK1.12 (CS#), R1.1, SJ1.2
EINK_RESET: D4.A, EINK1.10 (RES#), IC5.2 (/RESET), R8.1
EN: JP3.2, MS1.27 (EN)
GDR: EINK1.2 (GDR), Q5.1 (G)
GND: C1.2, C2.1, C3.2, C4.2, C6.1, C15.1, C16.1, C21.2, C22.1, C23.1, C24.1, D2.C, EINK1.8 (BSI), EINK1.17 (VSS), IC5.1 (GND), JP1.13, MS1.4 (GND), R4.2, SW1.A, SW1.A' (P1), U4.4 (VSS), X1.6 (GND), X1.MT1 (GND), X1.MT2 (GND)
H: JP2.8, MS1.19 (GPIO5), SJ3.1
I: JP2.7, MS1.20 (GPIO6), SJ2.1
J: JP2.6, MS1.21 (GPIO9), SJ1.1
K: JP2.5, MS1.22 (GPIO10), SJ4.1
MISO: JP1.4, MS1.13 (GPIOMISO), U4.2 (MISO), X1.7 (DATA_OUT)
MOSI: EINK1.14 (SDIO), JP1.5, MS1.12 (GPIOMOSI), U4.5 (MOSI), X1.3 (DATA_IN)
unnamed: JP1.7, MS1.10 (GPIOA5)
unnamed: C5.2, D1.C, D2.A
unnamed: C5.1, D3.A, L1.P$1 (1), Q5.3 (D)
unnamed: C16.2, EINK1.5 (VSH2)
unnamed: C2.2, EINK1.18 (VDD)
unnamed: C22.2, EINK1.20 (VSH1)
unnamed: D4.C, SJ5.1
unnamed: JP1.11, MS1.6 (GPIOA1)
unnamed: C6.2, EINK1.4 (VGL/NC)
unnamed: JP1.10, MS1.7 (GPIOA2)
unnamed: JP1.9, MS1.8 (GPIOA3)
unnamed: JP1.8, MS1.9 (GPIOA4)
unnamed: JP1.3, MS1.14 (GPIORX)
unnamed: JP1.2, MS1.15 (GPIOTX)
unnamed: JP1.1, MS1.16 (NC)
unnamed: JP2.10, MS1.17 (GPIOSDA)
unnamed: JP2.9, MS1.18 (GPIOSCL)
unnamed: JP2.4, MS1.23 (GPIO11)
unnamed: JP2.3, MS1.24 (GPIO12)
unnamed: JP2.2, MS1.25 (GPIO13)
unnamed: C23.2, EINK1.22 (VSL)
unnamed: C24.2, EINK1.24 (VCOM)
RESE: EINK1.3 (RESE), Q5.2 (S), R4.1
RESET: JP1.16, MS1.1 (!RESET), SJ5.2, SW1.B (S), SW1.B' (S1)
SCLK: EINK1.13 (SCK), JP1.6, MS1.11 (GPIOSCK), U4.6 (SCLK), X1.5 (SCLK)
SD_CS: R6.1, SJ3.2, X1.2 (CS)
SRAM_CS: R7.1, SJ2.2, U4.1 (#CS)
USB: JP2.1, MS1.26 (USB)
VBAT: JP3.1, MS1.28 (VBAT)
VGH: C3.1, D3.C, EINK1.21 (VGH)
VGL: C4.1, D1.A, EINK1.23 (VGL)

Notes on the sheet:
HEADER PINS
FRAMEBUFFER SRAM
SPI SRAM can be used to store the screen
data if the MCU doesn't have 6KB free SRAM
SD CARD

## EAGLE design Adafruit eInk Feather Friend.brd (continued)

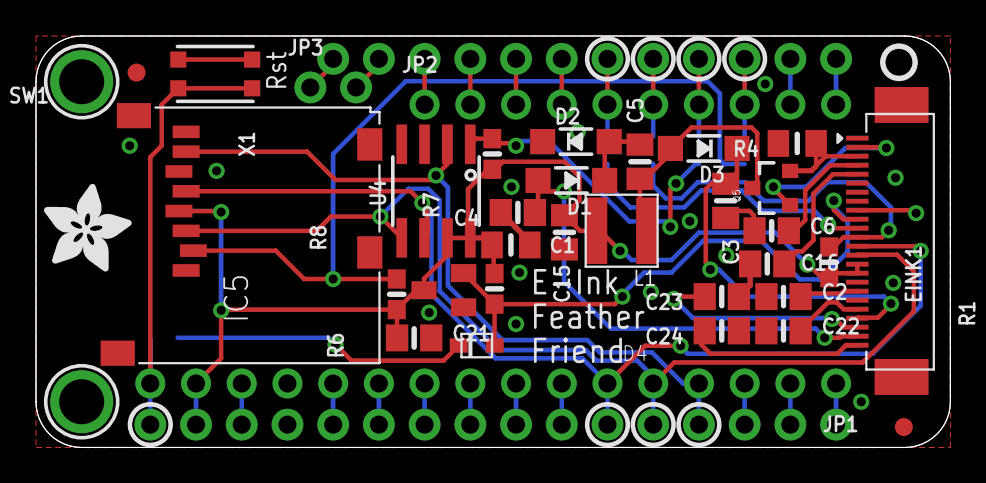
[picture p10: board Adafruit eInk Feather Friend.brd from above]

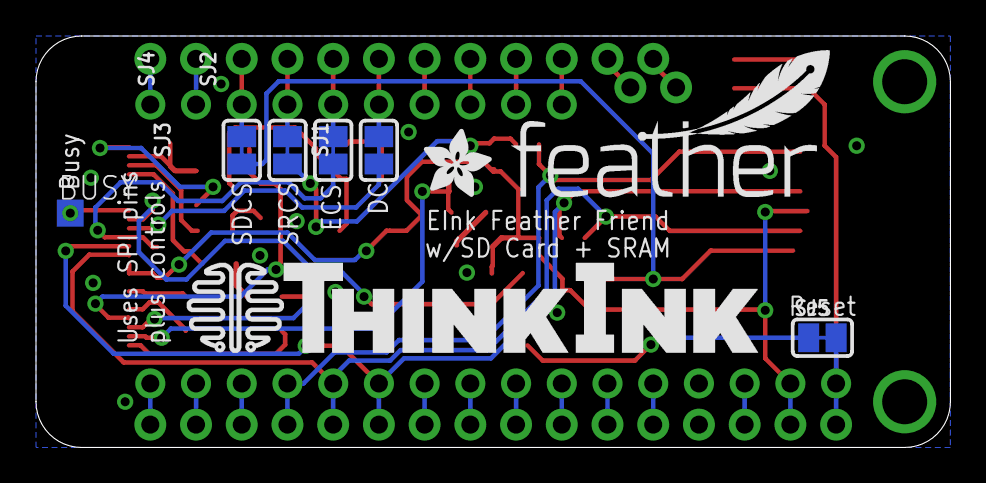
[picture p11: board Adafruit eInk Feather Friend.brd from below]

Board: 2 copper layers, 50.8 x 22.9 mm, 47 parts (9 on the bottom side), 47 nets.

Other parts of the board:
U$5: THINKINK_1.25IN
U$6: FEATHERLOGO_MED
U$8: ADAFRUIT_5MM
U$9: PCBFEAT-REV-040
U$17: ADAFRUIT_3.5MM

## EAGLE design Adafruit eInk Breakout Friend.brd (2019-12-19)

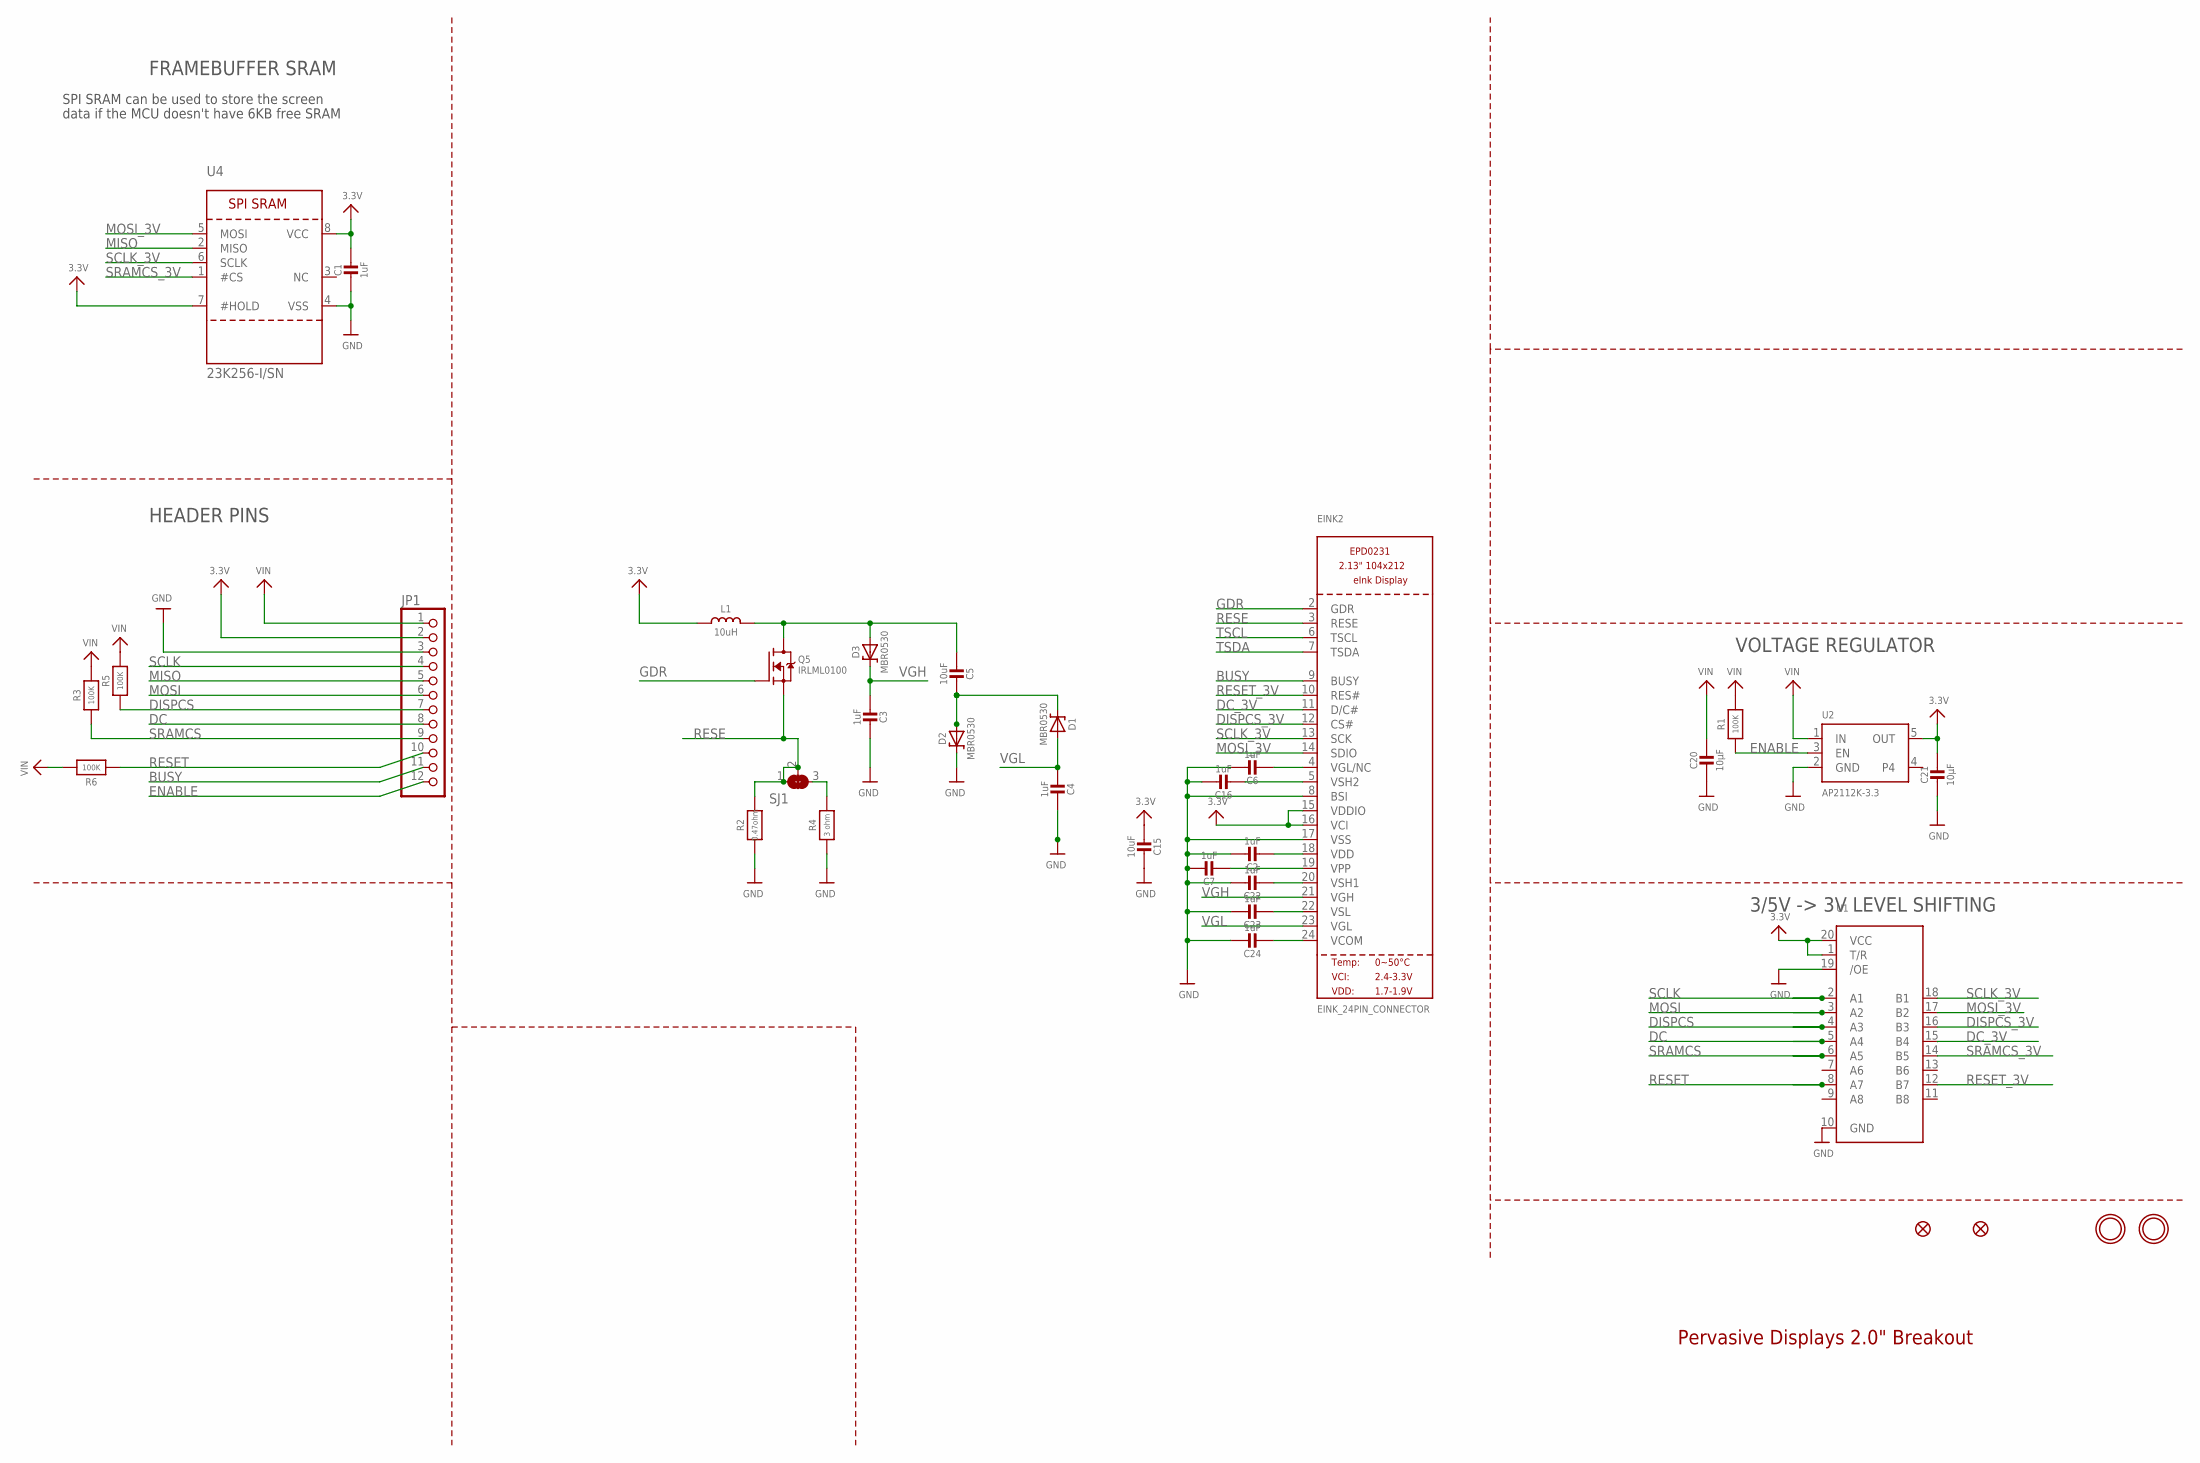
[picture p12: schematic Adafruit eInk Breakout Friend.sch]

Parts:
C1: 1uF; 0805_10MGAP
C2, C3, C4, C6, C7, C16, C22, C23, C24: 1uF; 0805-NO
C5, C15: 10uF; 0805-NO
C20, C21: 10µF; 0805-NO
D1, D2, D3: MBR0530; SOD-123
EINK2: EINK_24PIN_CONNECTOR; EINK_24PIN
FID2, FID3: FIDUCIAL_1MM
JP1: HEADER-1X1276MIL; 1X12_ROUND_76MIL
L1: 10uH; INDUCTOR_4X4MM_NR401
Q5: IRLML0100; SOT23-3
R1, R3, R5, R6: 100K; 0603-NO
R2: 0.47ohm; 0805-NO
R4: 3 ohm; 0805-NO
SJ1: SOLDERJUMPER_2WAY; SOLDERJUMPER_2WAY_OPEN_NOPASTE
U1: 74LCX245; TSSOP20
U2: AP2112K-3.3; SOT23-5
U4: 23K256-I/SN; SOIC8_150MIL
U$3, U$4: MOUNTINGHOLE2.5; MOUNTINGHOLE_2.5_PLATED

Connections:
3.3V: C1.1, C15.2, C21.1, EINK2.15 (VDDIO), EINK2.16 (VCI), JP1.2, L1.P$2 (2), U1.1 (T/R), U1.20 (VCC), U2.5 (OUT), U4.7 (#HOLD), U4.8 (VCC)
BUSY: EINK2.9 (BUSY), JP1.11
DC: JP1.8, U1.5 (A4)
DC_3V: EINK2.11 (D/C#), U1.15 (B4)
DISPCS: JP1.7, R5.1, U1.4 (A3)
DISPCS_3V: EINK2.12 (CS#), U1.16 (B3)
ENABLE: JP1.12, R1.1, U2.3 (EN)
GDR: EINK2.2 (GDR), Q5.1 (G)
GND: C1.2, C2.1, C3.2, C4.2, C6.1, C7.1, C15.1, C16.1, C20.2, C21.2, C22.1, C23.1, C24.1, D2.C, EINK2.8 (BSI), EINK2.17 (VSS), JP1.3, R2.2, R4.2, U1.10 (GND), U1.19 (/OE), U2.2 (GND), U4.4 (VSS)
MISO: JP1.5, U4.2 (MISO)
MOSI: JP1.6, U1.3 (A2)
MOSI_3V: EINK2.14 (SDIO), U1.17 (B2), U4.5 (MOSI)
unnamed: C7.2, EINK2.19 (VPP)
unnamed: C5.2, D1.C, D2.A
unnamed: C5.1, D3.A, L1.P$1 (1), Q5.3 (D)
unnamed: C16.2, EINK2.5 (VSH2)
unnamed: C2.2, EINK2.18 (VDD)
unnamed: C22.2, EINK2.20 (VSH1)
unnamed: R4.1, SJ1.3
unnamed: C6.2, EINK2.4 (VGL/NC)
unnamed: C23.2, EINK2.22 (VSL)
unnamed: C24.2, EINK2.24 (VCOM)
RESE: EINK2.3 (RESE), Q5.2 (S), R2.1, SJ1.1, SJ1.2
RESET: JP1.10, R6.1, U1.8 (A7)
RESET_3V: EINK2.10 (RES#), U1.12 (B7)
SCLK: JP1.4, U1.2 (A1)
SCLK_3V: EINK2.13 (SCK), U1.18 (B1), U4.6 (SCLK)
SRAMCS: JP1.9, R3.1, U1.6 (A5)
SRAMCS_3V: U1.14 (B5), U4.1 (#CS)
TSCL: EINK2.6 (TSCL)
TSDA: EINK2.7 (TSDA)
VGH: C3.1, D3.C, EINK2.21 (VGH)
VGL: C4.1, D1.A, EINK2.23 (VGL)
VIN: C20.1, JP1.1, R1.2, R3.2, R5.2, R6.2, U2.1 (IN)

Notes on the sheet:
Pervasive Displays 2.0" Breakout
VOLTAGE REGULATOR
3/5V -> 3V LEVEL SHIFTING
HEADER PINS
FRAMEBUFFER SRAM
SPI SRAM can be used to store the screen
data if the MCU doesn't have 6KB free SRAM



Board: 2 copper layers, 34.3 x 21.6 mm, 37 parts (2 on the bottom side), 32 nets.

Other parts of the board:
U$2: ADAFRUIT_3.5MM
U$9: PCBFEAT-REV-040

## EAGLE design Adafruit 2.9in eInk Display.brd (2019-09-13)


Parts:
C1: 1uF; 0805_10MGAP
C2, C3, C4, C6, C7, C16, C22, C23, C24: 1uF; 0805-NO
C5: 4.7uF/25V; 0805-NO
C15: 10uF/10V+; 0805-NO
C20, C21: 10µF; 0805-NO
D1, D2, D3: MBR0530; SOD-123
EINK2: EINK_24PIN_290IN; EINK_290IN
FID1, FID2, FID3: FIDUCIAL_1MM
IC1: 74HCT245DW; SO20W
JP2: HEADER-1X13; 1X13_ROUND_70
L1: 10uH; INDUCTOR_4X4MM_NR401
Q5: IRLML0100; SOT23-3
R1, R2, R3, R5, R6: 100K; 0805-NO
R4: 0.47ohm; 0805_10MGAP
R7: DNP; 0805_10MGAP
U2: AP2112K-3.3; SOT23-5
U4: 23K256-I/SN; SOIC8_150MIL
U$3, U$4, U$5, U$6: MOUNTINGHOLE2.5; MOUNTINGHOLE_2.5_PLATED
X1: MICROSD

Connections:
3.3V: C1.1, C15.2, C21.1, EINK2.15 (VDDIO), EINK2.16 (VCI), IC1.1 (DIR), IC1.20 (VCC), JP2.2, L1.P$2 (2), U2.5 (OUT), U4.7 (#HOLD), U4.8 (VCC), X1.4 (SD_VDD)
BUSY: EINK2.9 (BUSY), JP2.12
DC: IC1.5 (A4), JP2.8
DC_3V: EINK2.11 (D/C#), IC1.15 (B4)
DISPCS: IC1.4 (A3), JP2.7, R5.1
DISPCS_3V: EINK2.12 (CS#), IC1.16 (B3)
ENABLE: JP2.13, R1.1, U2.3 (EN)
GDR: EINK2.2 (GDR), Q5.1 (G)
GND: C1.2, C2.1, C3.2, C4.2, C6.1, C7.1, C15.1, C16.1, C20.2, C21.2, C22.1, C23.1, C24.1, D2.C, EINK2.8 (BSI), EINK2.17 (VSS), IC1.10 (GND), IC1.19 (G), JP2.3, R4.2, R7.2, U2.2 (GND), U4.4 (VSS), X1.6 (GND), X1.MT1 (GND), X1.MT2 (GND)
MISO: JP2.5, U4.2 (MISO), X1.7 (DATA_OUT)
MOSI: IC1.3 (A2), JP2.6
MOSI_3V: EINK2.14 (SDIO), IC1.17 (B2), U4.5 (MOSI), X1.3 (DATA_IN)
unnamed: C7.2, EINK2.19 (VPP)
unnamed: C5.2, D1.C, D2.A
unnamed: C5.1, D3.A, L1.P$1 (1), Q5.3 (D)
unnamed: C16.2, EINK2.5 (VSH2)
unnamed: C2.2, EINK2.18 (VDD)
unnamed: C22.2, EINK2.20 (VSH1)
unnamed: C6.2, EINK2.4 (VGL/NC)
unnamed: C23.2, EINK2.22 (VSL)
unnamed: C24.2, EINK2.24 (VCOM)
RESE: EINK2.3 (RESE), Q5.2 (S), R4.1, R7.1
RESET: IC1.8 (A7), JP2.11, R6.1
RESET_3V: EINK2.10 (RES#), IC1.12 (B7)
SCLK: IC1.2 (A1), JP2.4
SCLK_3V: EINK2.13 (SCK), IC1.18 (B1), U4.6 (SCLK), X1.5 (SCLK)
SDCS: IC1.7 (A6), JP2.10, R2.1
SDCS_3V: IC1.13 (B6), X1.2 (CS)
SRAMCS: IC1.6 (A5), JP2.9, R3.1
SRAMCS_3V: IC1.14 (B5), U4.1 (#CS)
TSCL: EINK2.6 (TSCL)
TSDA: EINK2.7 (TSDA)
VGH: C3.1, D3.C, EINK2.21 (VGH)
VGL: C4.1, D1.A, EINK2.23 (VGL)
VIN: C20.1, JP2.1, R1.2, R2.2, R3.2, R5.2, R6.2, U2.1 (IN)

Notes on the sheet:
2.9 e-Ink" Breakout
VOLTAGE REGULATOR
3/5V -> 3V LEVEL SHIFTING
HEADER PINS
FRAMEBUFFER SRAM
SPI SRAM can be used to store the screen
data if the MCU doesn't have 6KB free SRAM
SD CARD


Board: 2 copper layers, 80.0 x 47.0 mm, 41 parts (1 on the bottom side), 33 nets.

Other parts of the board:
U$9: PCBFEAT-REV-040
U$39: ADAFRUIT_TEXT_30MM

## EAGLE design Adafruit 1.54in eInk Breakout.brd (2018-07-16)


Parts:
C1: 1uF; 0805_10MGAP
C2, C6: 1uF/10V; 0805-NO
C3, C4, C16, C22, C23: 1uF/25V; 0805-NO
C5: 4.7uF/25V; 0805-NO
C7, C8: 1uF; 0805-NO
C15: 10uF/10V+; 0805-NO
C20, C21: 10µF; 0805-NO
C24: 1uF/6V; 0805-NO
D1, D2, D3: MBR0530; SOD-123
EINK1: EINK_EPD0231EINK_154IN_200X200; EINK_154IN
FID1, FID2, FID3: FIDUCIAL_1MM
IC1: 74LVC245PW; TSSOP20
JP2: HEADER-1X13; 1X13_ROUND_70
L1: 10uH; INDUCTOR_4X4MM_NR401
Q5: IRLML0100; SOT23-3
R1, R2, R3, R5, R6: 100K; 0805-NO
R4: 0.47ohm; 0805_10MGAP
U2: MIC5225-3.3; SOT23-5
U4: 23K640-I/SN; SOIC8_150MIL
U$3, U$4, U$5, U$6: MOUNTINGHOLE2.5; MOUNTINGHOLE_2.5_PLATED
X1: MICROSD

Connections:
3.3V: C1.1, C7.1, C8.1, C15.2, C21.1, EINK1.15 (VDDIO), EINK1.16 (VCI), IC1.1 (DIR), IC1.20 (VCC), JP2.2, L1.P$2 (2), U2.5 (OUT), U4.7 (#HOLD), U4.8 (VCC), X1.4 (SD_VDD)
BUSY: EINK1.9 (BUSY), JP2.12
DC: IC1.5 (A4), JP2.8
DC_3V: EINK1.11 (D/C#), IC1.15 (B4)
DISPCS: IC1.6 (A5), JP2.7, R5.1
DISPCS_3V: EINK1.12 (CS#), IC1.14 (B5)
ENABLE: JP2.13, R1.1, U2.3 (EN)
GDR: EINK1.2 (GDR), Q5.1 (G)
GND: C1.2, C2.1, C3.2, C4.2, C6.1, C7.2, C8.2, C15.1, C16.1, C20.2, C21.2, C22.1, C23.1, C24.1, D2.C, EINK1.8 (BSI), EINK1.17 (VSS), IC1.10 (GND), IC1.19 (G), JP2.3, R4.2, U2.2 (GND), U4.4 (VSS), X1.6 (GND), X1.MT1 (GND), X1.MT2 (GND)
MISO: JP2.5, U4.2 (MISO), X1.7 (DATA_OUT)
MOSI: IC1.7 (A6), JP2.6
MOSI_3V: EINK1.14 (SDIO), IC1.13 (B6), U4.5 (MOSI), X1.3 (DATA_IN)
unnamed: C5.2, D1.C, D2.A
unnamed: C5.1, D3.A, L1.P$1 (1), Q5.3 (D)
unnamed: C16.2, EINK1.5 (VSH2)
unnamed: C2.2, EINK1.18 (VDD)
unnamed: C22.2, EINK1.20 (VSH1)
unnamed: C6.2, EINK1.4 (VGL/NC)
unnamed: C23.2, EINK1.22 (VSL)
unnamed: C24.2, EINK1.24 (VCOM)
RESE: EINK1.3 (RESE), Q5.2 (S), R4.1
RESET: IC1.2 (A1), JP2.11, R6.1
RESET_3V: EINK1.10 (RES#), IC1.18 (B1)
SCLK: IC1.8 (A7), JP2.4
SCLK_3V: EINK1.13 (SCK), IC1.12 (B7), U4.6 (SCLK), X1.5 (SCLK)
SDCS: IC1.3 (A2), JP2.10, R2.1
SDCS_3V: IC1.17 (B2), X1.2 (CS)
SRAMCS: IC1.4 (A3), JP2.9, R3.1
SRAMCS_3V: IC1.16 (B3), U4.1 (#CS)
TSCL: EINK1.6 (TSCL)
TSDA: EINK1.7 (TSDA)
VGH: C3.1, D3.C, EINK1.21 (VGH)
VGL: C4.1, D1.A, EINK1.23 (VGL)
VIN: C20.1, JP2.1, R1.2, R2.2, R3.2, R5.2, R6.2, U2.1 (IN)

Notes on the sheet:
VOLTAGE REGULATOR
3/5V -> 3V LEVEL SHIFTING
HEADER PINS
FRAMEBUFFER SRAM
SPI SRAM can be used to store the screen
data if the MCU doesn't have 6KB free SRAM
SD CARD



Board: 2 copper layers, 43.2 x 43.2 mm, 41 parts (36 on the bottom side), 32 nets.

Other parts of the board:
U$9: PCBFEAT-REV-040
U$28: ADAFRUIT_TEXT_20MM

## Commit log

2019-02-13 Adding 2.7" and 2.13" PCB files
    [Adafruit 2.13in Tri-Color eInk Display.brd, Adafruit 2.13in Tri-Color eInk Display.sch, Adafruit 2.7in Tri-Color eInk Display.brd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]
2019-08-07 adding 2.13in featherwing
    [Adafruit 2.13in Tri-Color eInk FeatherWing.brd, Adafruit 2.13in Tri-Color eInk FeatherWing.sch]
2019-09-13 added 2.9" display
    [Adafruit 2.9in eInk Display.brd, Adafruit 2.9in eInk Display.sch]
2019-12-19 Adding PCB files for eInk Friends
    [Adafruit eInk Breakout Friend.brd, Adafruit eInk Breakout Friend.sch, Adafruit eInk Feather Friend.brd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]
2020-10-29 Added 2.9 inch eInk FeatherWing
    [Adafruit 2.9in eInk FeatherWing.brd, Adafruit 2.9in eInk FeatherWing.sch]
2023-02-21 adding 2.13 EYESPI files
    [2.13in Tri-Color eInk with EYESPI.brd, 2.13in Tri-Color eInk with EYESPI.sch]
2023-02-21 adding Adafruit to file names
    [Adafruit 2.13in Tri-Color eInk with EYESPI.brd, Adafruit 2.13in Tri-Color eInk with EYESPI.sch]
2023-03-31 Adding 2.7" eyespi
    [Adafruit 2.7in Tri-Color eInk Display with EYESPI.brd, Adafruit 2.7in Tri-Color eInk Display with EYESPI.sch]
2024-02-07 adding 1.54 eink with eyespi
    [Adafruit 1.54in eInk Breakout with EYESPI.brd, Adafruit 1.54in eInk Breakout with EYESPI.sch]

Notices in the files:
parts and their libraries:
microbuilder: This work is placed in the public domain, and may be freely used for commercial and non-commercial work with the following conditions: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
